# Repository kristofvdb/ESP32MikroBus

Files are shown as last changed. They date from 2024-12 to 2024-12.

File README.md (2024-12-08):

# ESP32MikroBus

Minimal ESP32C6 project with Mikrobus and Qwiic header 

I needed a minimal ESP32 project with MikroBus.
Since I couldn't find any, I decided to create it myself.

I also wanted to be able to solder it myself, otherwise I could have made the design more compact.
That is also the reason why there are only components on the top side.

Many thanks to the other folks that also made their design open source, which speeded up this design.

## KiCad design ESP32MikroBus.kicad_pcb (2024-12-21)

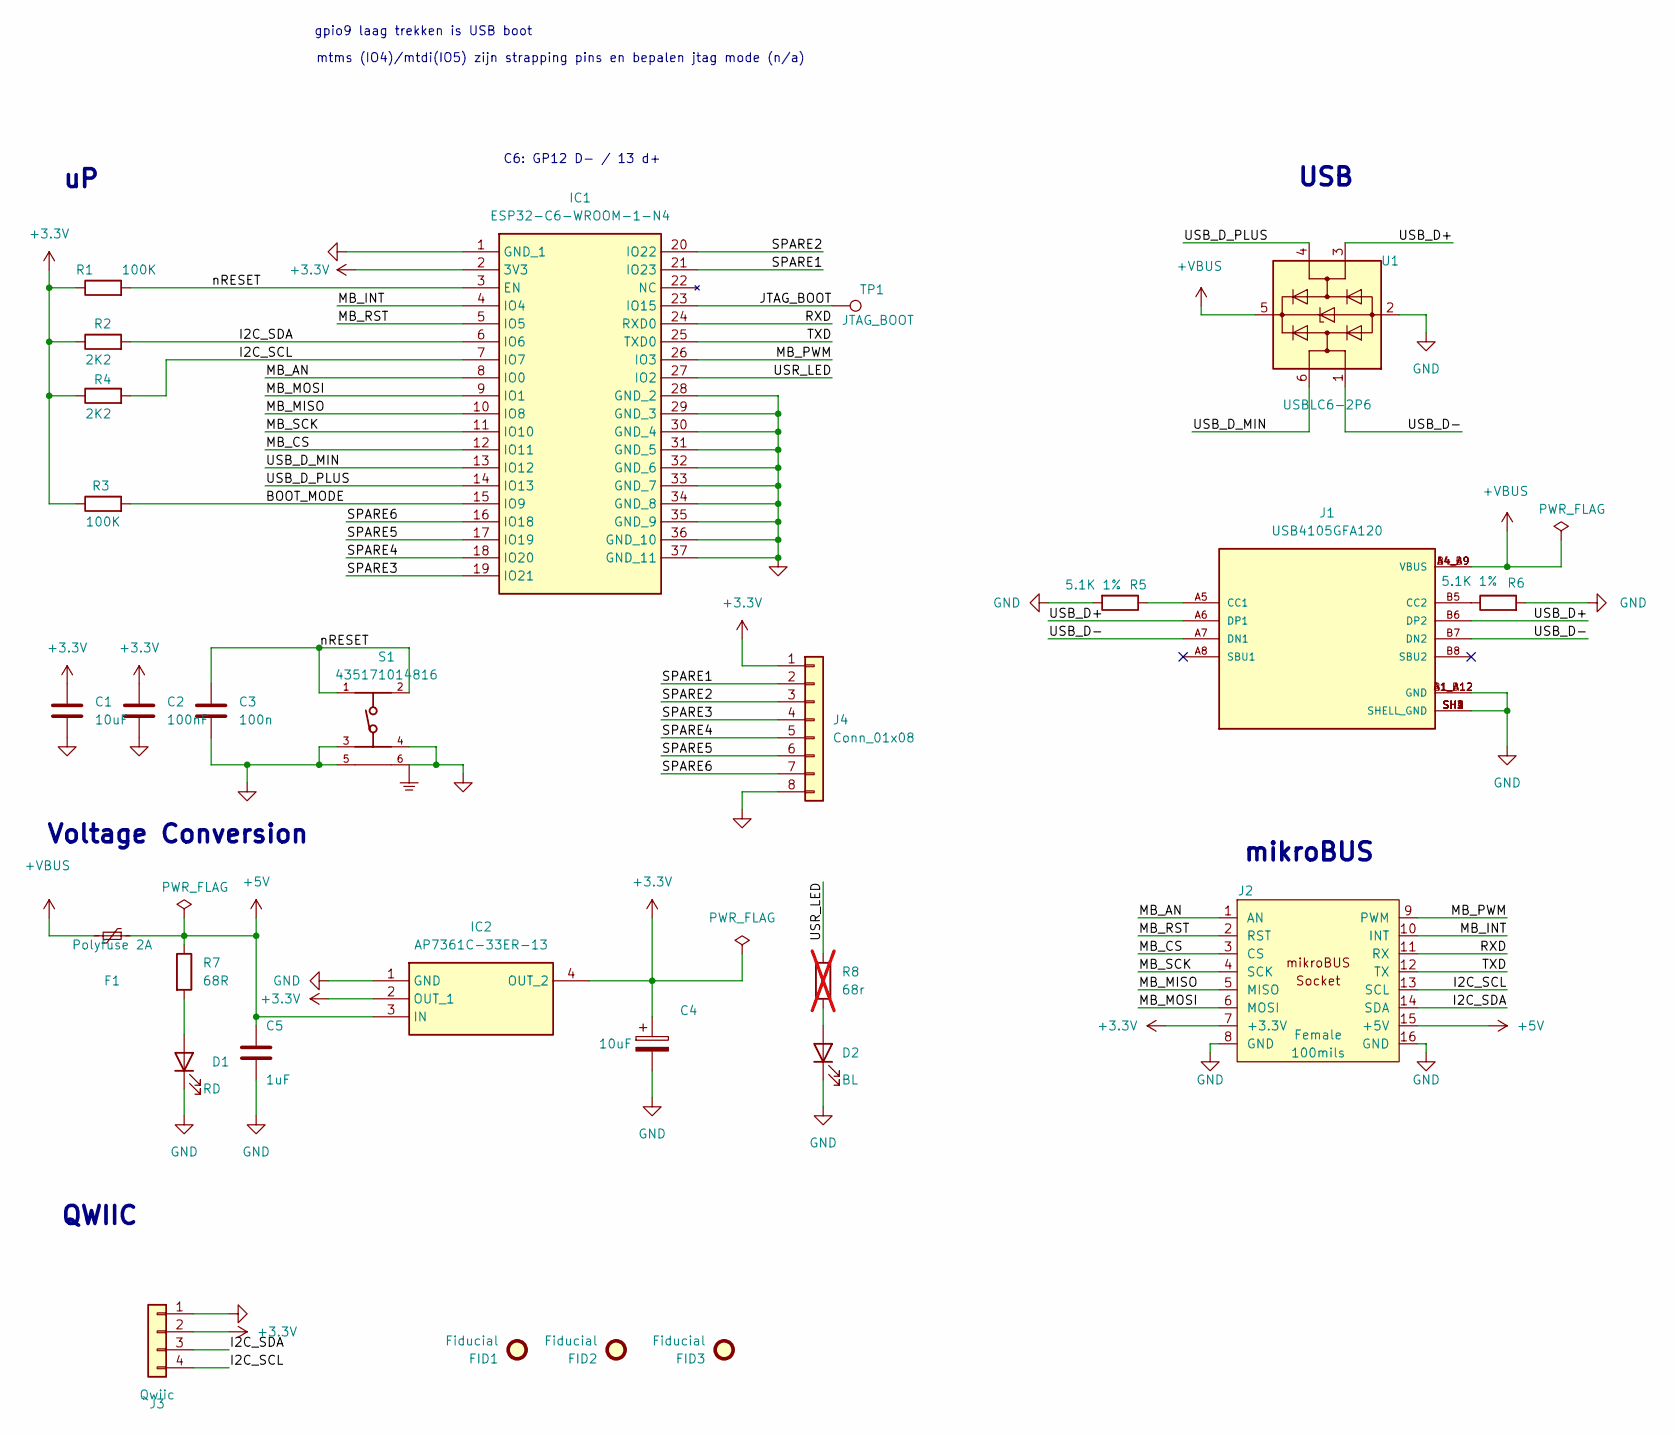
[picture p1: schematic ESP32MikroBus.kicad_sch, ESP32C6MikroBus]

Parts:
C1, C4: 10uF; C_0603_1608Metric
C2: 100nF; C_0603_1608Metric
C3: 100n; C_0603_1608Metric
C5: 1uF; C_0603_1608Metric
D1: RD; LED_0805_2012Metric
D2: BL; LED_0805_2012Metric
F1: Polyfuse 2A; FUSC3216X100N
FID1, FID2, FID3: Fiducial; Fiducial_0.5mm_Mask1.5mm
IC1: ESP32-C6-WROOM-1-N4; ESP32C6WROOM1N4; Mouser Part Number 356-ESP32C6WROOM1N4
IC2: AP7361C-33ER-13; SOT230P700X180-4N; Mouser Part Number 621-AP7361C-33ER-13
J1: USB4105GFA120; GCT_USB4105GFA120; PARTREV B3
J2: CON_HDR_MIKROBUS_SOCKET_TH; Voltage 350V
J3: Qwiic; SPARKFUN_PRT-14417
J4: Conn_01x08; PinHeader_1x08_P1.27mm_Vertical
R1, R3: 100K; R_0603_1608Metric
R2, R4: 2K2; R_0603_1608Metric
R5, R6: 5.1K 1%; R_0603_1608Metric
R7: 68R; R_0603_1608Metric
R8: 68r; R_0603_1608Metric; not fitted
S1: 435171014816; PART-NUMBER 435171014816
TP1: JTAG_BOOT; TestPoint_Pad_D1.5mm
U1: USBLC6-2P6; SOT-666

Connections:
+3.3V: C1.1, C2.1, C4.1, IC1.2 (3V3), IC2.2 (OUT_1), IC2.4 (OUT_2), J2.7 (+3.3V), J3.2, J4.1, R1.1, R2.1, R3.1, R4.1
+5V: C5.1, F1.1, IC2.3 (IN), J2.15 (+5V), R7.1
+VBUS: F1.2, J1.A4_B9 (VBUS), J1.B4_A9 (VBUS), U1.5 (VBUS)
/BOOT_MODE: IC1.15 (IO9), R3.2
/I2C_SCL: IC1.7 (IO7), J2.13 (SCL), J3.4, R4.2
/I2C_SDA: IC1.6 (IO6), J2.14 (SDA), J3.3, R2.2
/JTAG_BOOT: IC1.23 (IO15), TP1.1
/MB_AN: IC1.8 (IO0), J2.1 (AN)
/MB_CS: IC1.12 (IO11), J2.3 (CS)
/MB_INT: IC1.4 (IO4), J2.10 (INT)
/MB_MISO: IC1.10 (IO8), J2.5 (MISO)
/MB_MOSI: IC1.9 (IO1), J2.6 (MOSI)
/MB_PWM: IC1.26 (IO3), J2.9 (PWM)
/MB_RST: IC1.5 (IO5), J2.2 (RST)
/MB_SCK: IC1.11 (IO10), J2.4 (SCK)
/RXD: IC1.24 (RXD0), J2.11 (RX)
/SPARE1: IC1.21 (IO23), J4.2
/SPARE2: IC1.20 (IO22), J4.3
/SPARE3: IC1.19 (IO21), J4.4
/SPARE4: IC1.18 (IO20), J4.5
/SPARE5: IC1.17 (IO19), J4.6
/SPARE6: IC1.16 (IO18), J4.7
/TXD: IC1.25 (TXD0), J2.12 (TX)
/USB_D+: J1.A6 (DP1), J1.B6 (DP2), U1.3 (I/O2)
/USB_D-: J1.A7 (DN1), J1.B7 (DN2), U1.1 (I/O1)
/USB_D_MIN: IC1.13 (IO12), U1.6 (I/O1)
/USB_D_PLUS: IC1.14 (IO13), U1.4 (I/O2)
/USR_LED: IC1.27 (IO2), R8.1
/nRESET: C3.1, IC1.3 (EN), R1.2, S1.1, S1.2
GND: C1.2, C2.2, C3.2, C4.2, C5.2, D1.1 (K), D2.1 (K), IC1.1 (GND_1), IC1.28 (GND_2), IC1.29 (GND_3), IC1.30 (GND_4), IC1.31 (GND_5), IC1.32 (GND_6), IC1.33 (GND_7), IC1.34 (GND_8), IC1.35 (GND_9), IC1.36 (GND_10), IC1.37 (GND_11), IC2.1 (GND), J1.A1_B12 (GND), J1.B1_A12 (GND), J1.SH1 (SHELL_GND), J1.SH2 (SHELL_GND), J1.SH3 (SHELL_GND), J1.SH4 (SHELL_GND), J2.8 (GND), J2.16 (GND), J3.1, J4.8, R5.2, R6.2, S1.3, S1.4, S1.5, S1.6, U1.2 (GND)
unnamed: D1.2 (A), R7.2
unnamed: D2.2 (A), R8.2
unnamed: J1.A5 (CC1), R5.1
unnamed: J1.B5 (CC2), R6.1

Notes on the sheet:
mikroBUS
QWIIC
Voltage Conversion
mtms (IO4)/mtdi(IO5) zijn strapping pins en bepalen jtag mode (n/a)
USB
gpio9 laag trekken is USB boot
C6: GP12 D- / 13 d+

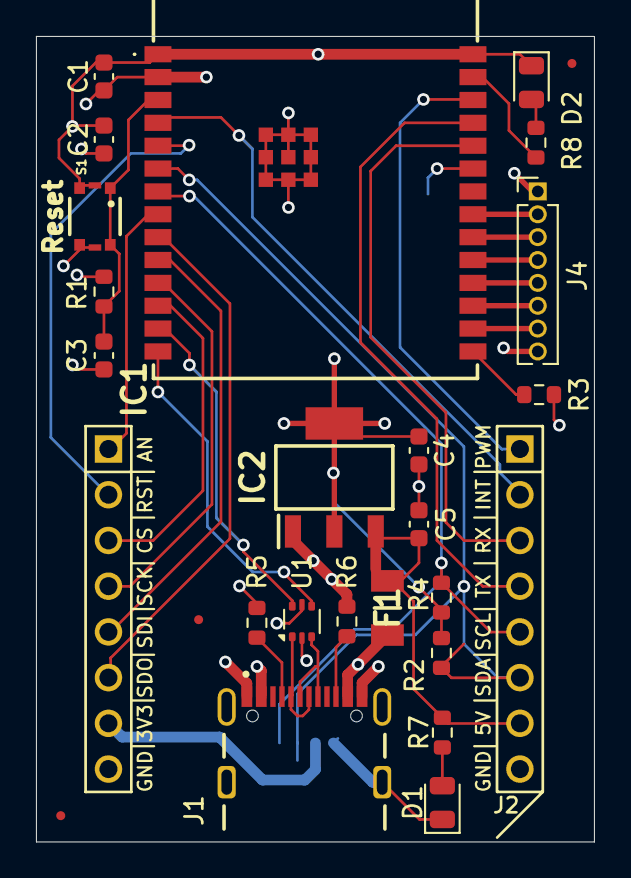
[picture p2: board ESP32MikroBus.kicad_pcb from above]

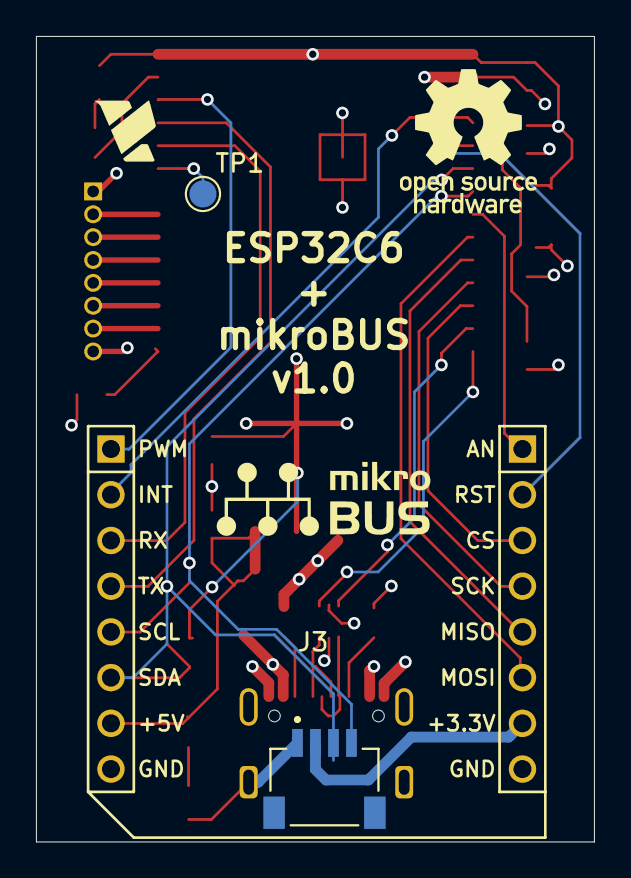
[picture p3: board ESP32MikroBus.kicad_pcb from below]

Board: 4 copper layers, 31.0 x 44.8 mm, 28 parts (2 on the bottom side), 34 nets.

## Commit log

2024-12-08 Schematic ready to start PCB design
    [ESP32MikroBus.kicad_pcb, ESP32MikroBus.kicad_sch]
2024-12-08 PCB Layout v1.0 ready for verification by PCBWay
    [ESP32MikroBus.kicad_pcb, ESP32MikroBus.kicad_sch]
2024-12-08 Minor update, mainly cosmetical + vbus not connected
    [ESP32MikroBus.kicad_pcb, ESP32MikroBus.kicad_sch]
2024-12-21 Changed c1 to 10uF, more attention to power traces, fixed copper plane and qwiic connector
    [ESP32MikroBus.kicad_pcb, ESP32MikroBus.kicad_sch]
